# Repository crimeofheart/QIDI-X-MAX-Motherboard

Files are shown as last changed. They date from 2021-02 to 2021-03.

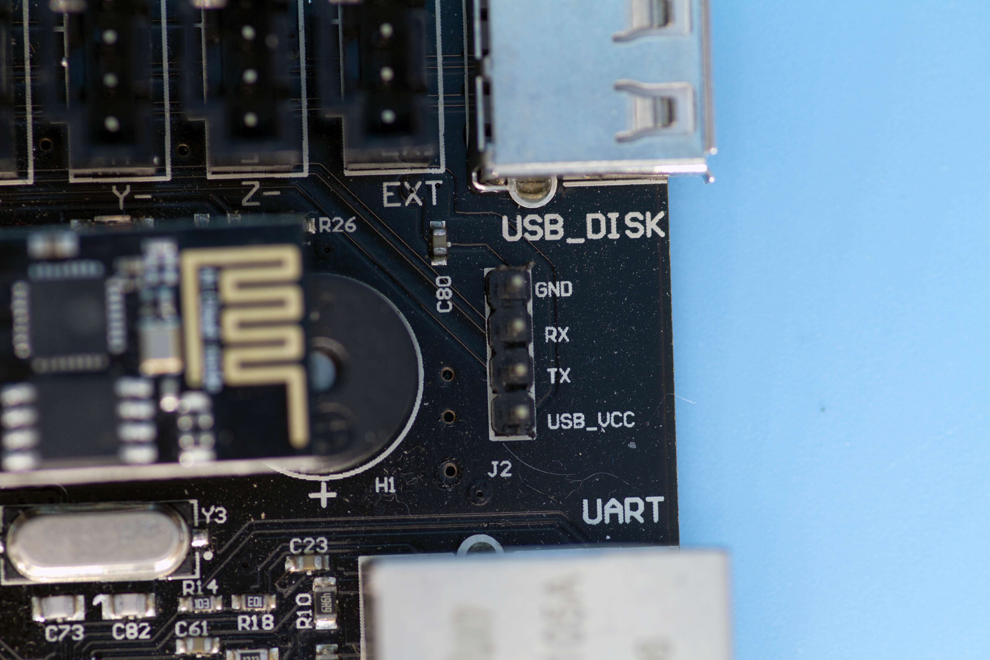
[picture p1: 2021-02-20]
Images/UART for USB to serial raspberry connection.jpg

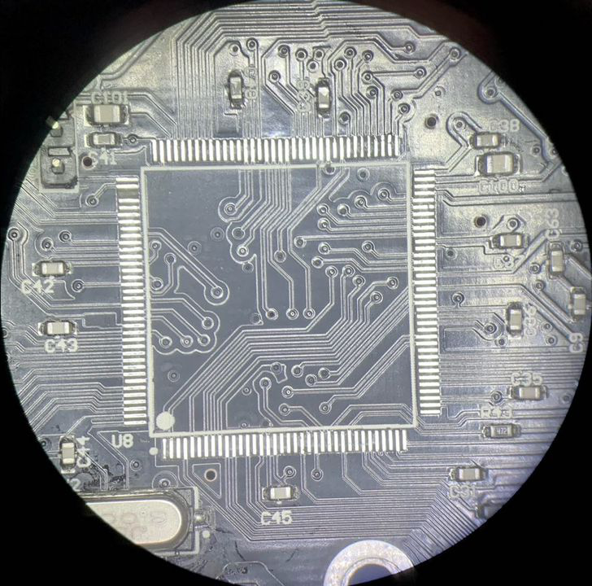
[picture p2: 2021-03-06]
Images/PCB Under STM32.jpg

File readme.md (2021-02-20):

QIDI X-MAX Motherboard Project
Starting

To download this project to your computer:

    Install GIT: https://git-scm.com/downloads
    Go into your main project directory, open commad line and run:
    git clone https://github.com/your_username/your_project.git

Using Git in Altium

    Save: Once you make any changes, save the file or project
    Commit: Right click on the file or project, then Version Control -> Commit. Add a note what changes you have done. This not will be still local until you do not push the changes. See the next step.
    Push: When you would like to upload all the changes to github, right click on the file / project -> Version Control -> Push
    Check: Go to your github to see if everything was uploaded correctly

Using Git from command line (Manually)

    Open cmd: Once you make some updates, go into your project directory, open commad line and run:
    git status #this will show you what changes you have done
    git add [path/file] #this will prepare that specific file for commit, to add all files at once, use add .
    git commit -m "Change description" #this will commit the changes with specific description
    git push origin master # this will copy your changes to Github

Download the latest changes

If you would like to download the latest files from Github, then:

    git pull origin master # this will download the latest files from Github to your local computer

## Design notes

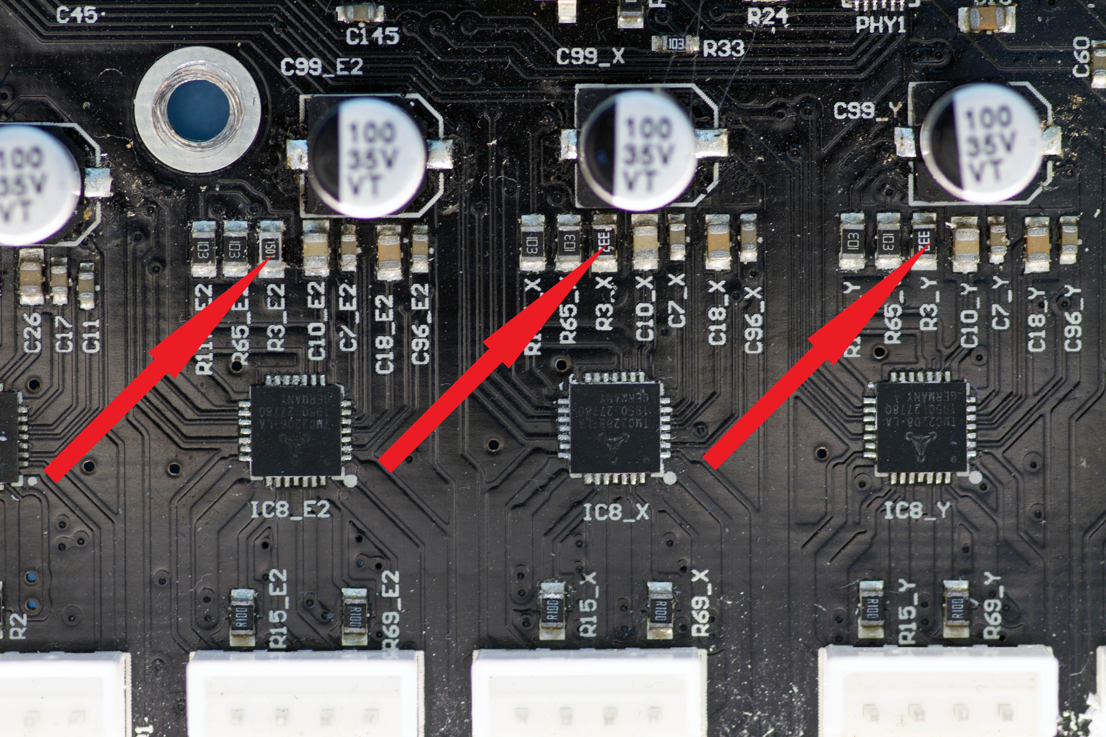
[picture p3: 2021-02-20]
Images/Motor drivers TMC2208.jpg

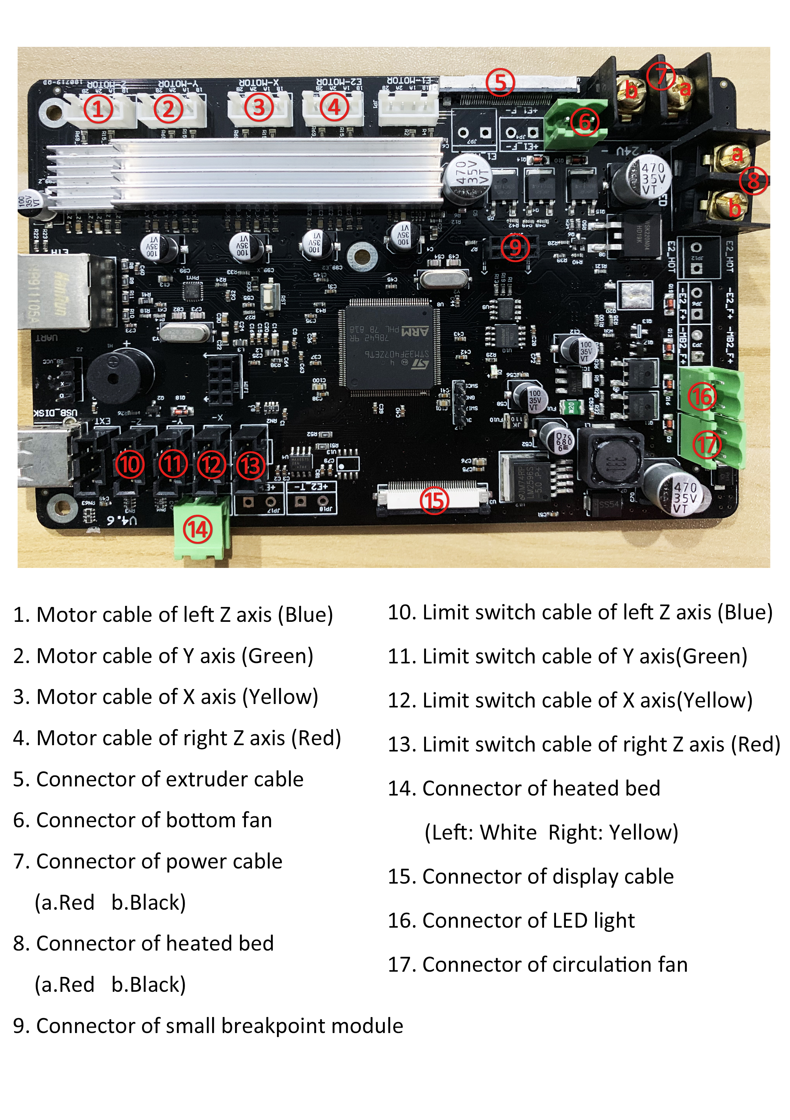
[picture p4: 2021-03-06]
Images/x-plus max mainboard connetion.jpg

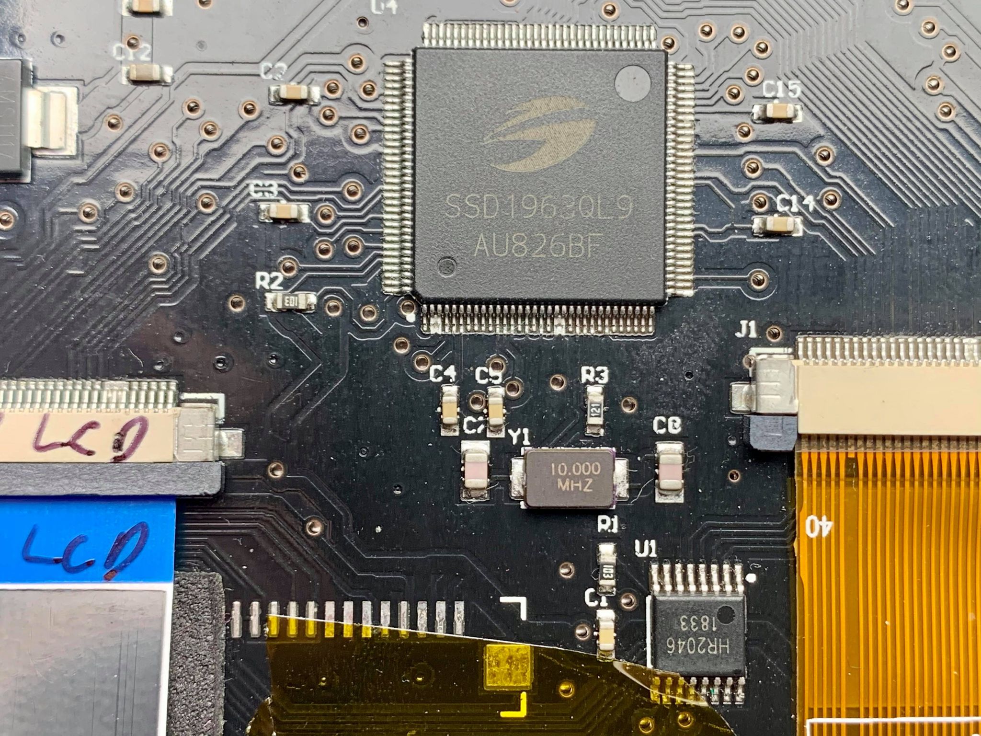
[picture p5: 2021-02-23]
Images/SSD1963QL9 LCD Driver.jpg

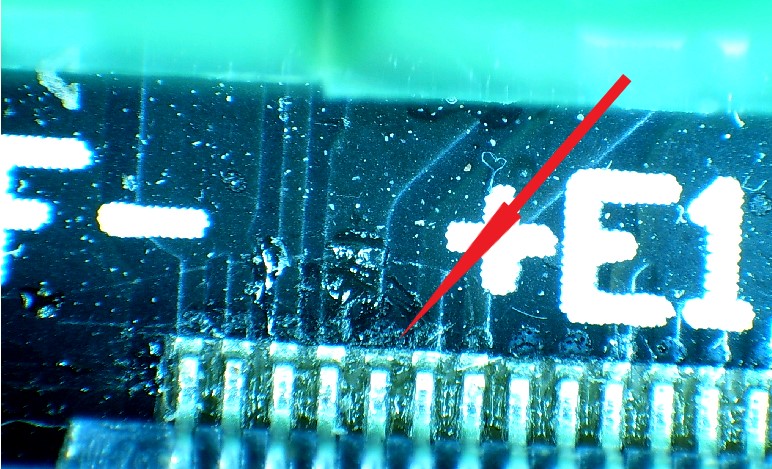
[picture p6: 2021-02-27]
Images/bed level sensor.jpg

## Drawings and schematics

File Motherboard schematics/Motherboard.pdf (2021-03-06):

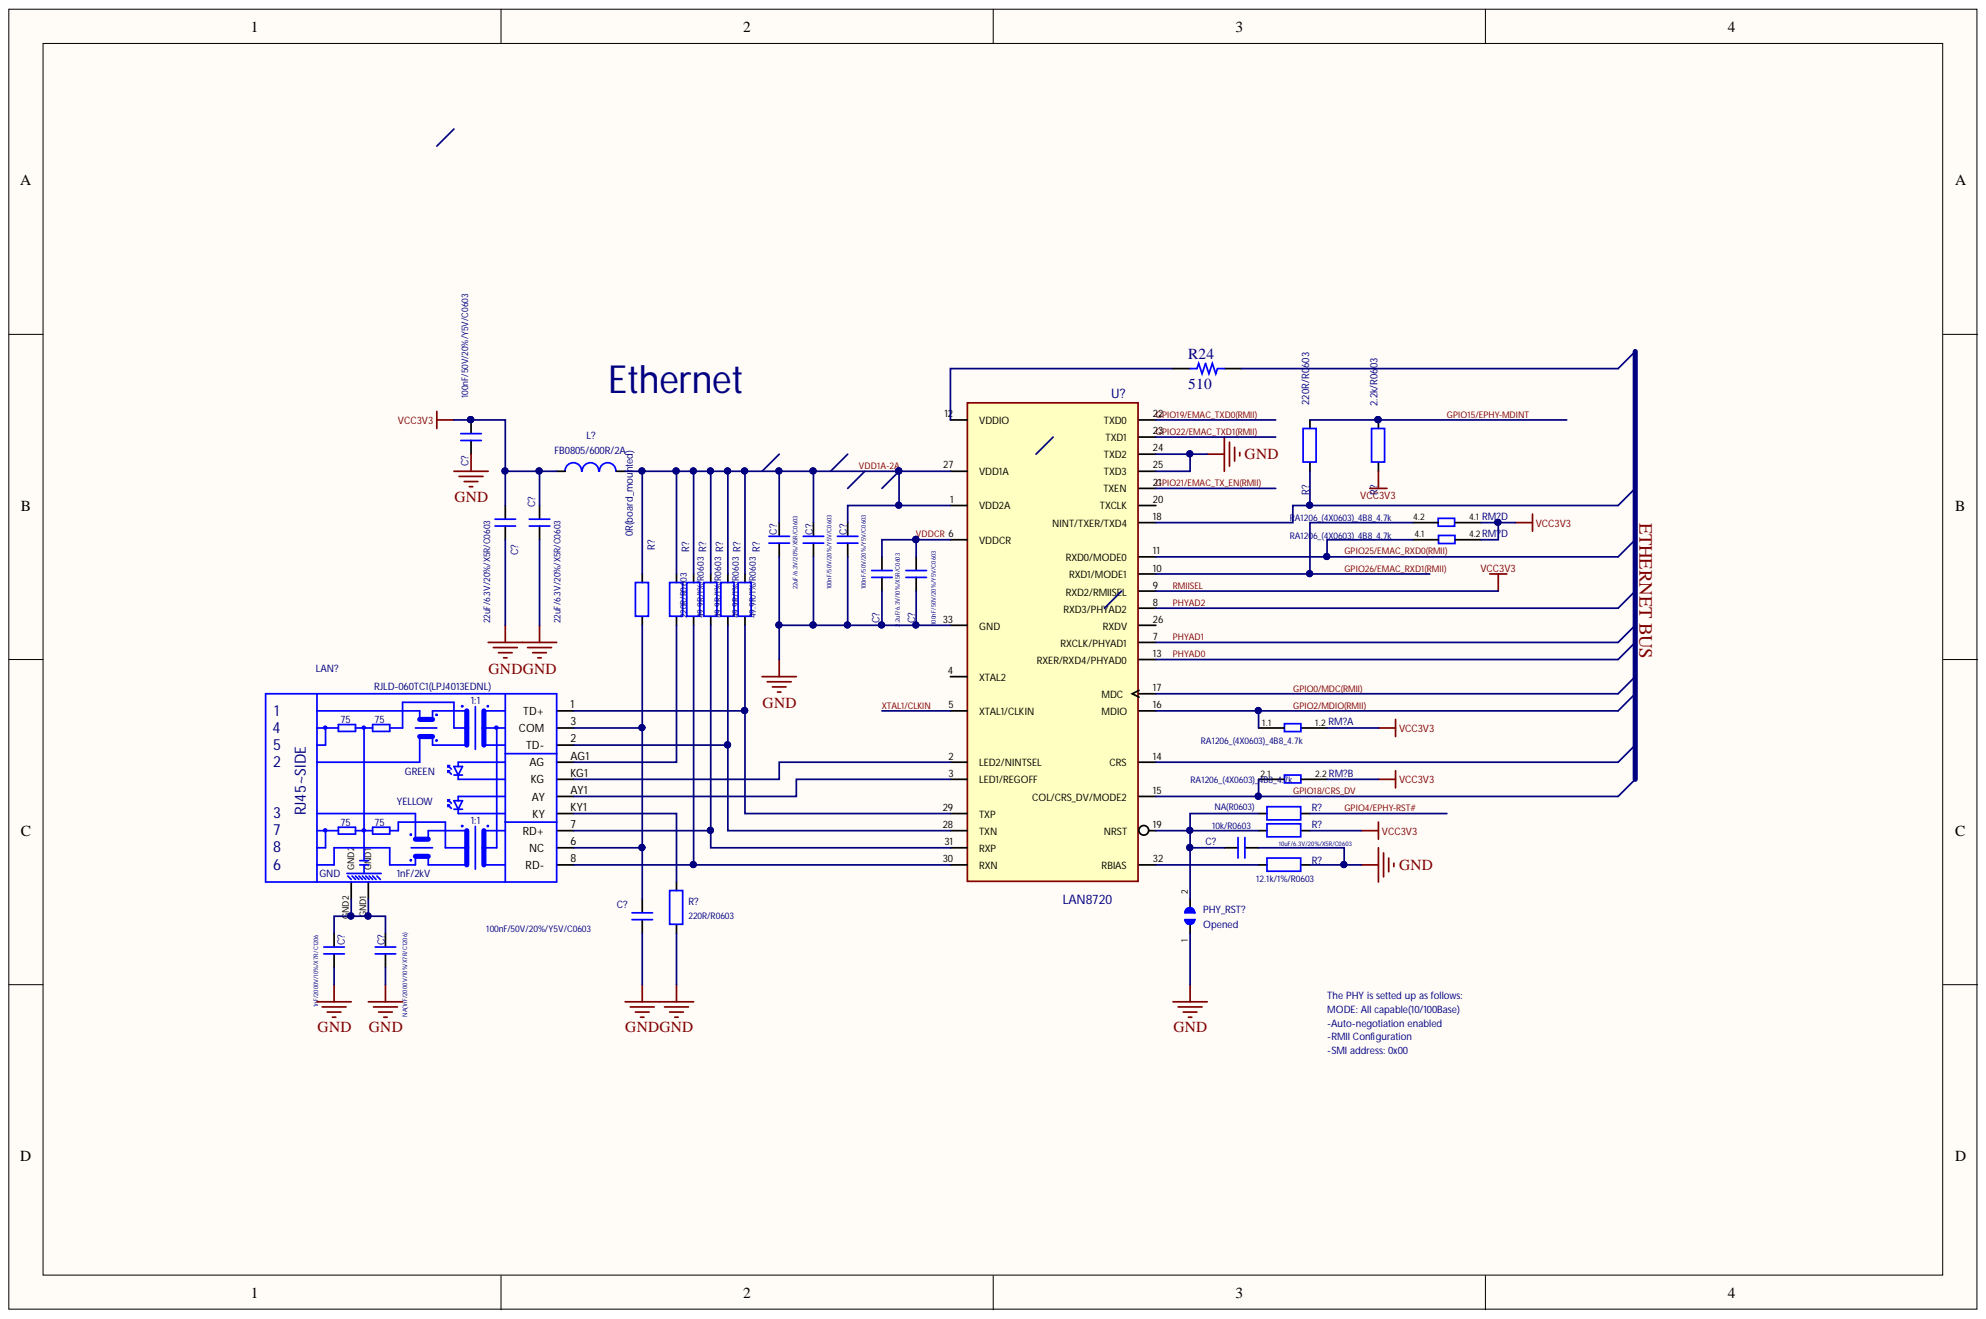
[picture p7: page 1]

V D DCR 6 | | RA1 206_(4X0603)_4B 1 1 | 8_4.7k | 0(RM I I )

A G 1

A Y 1
KY 1 | | 29

Y is setted up as fol

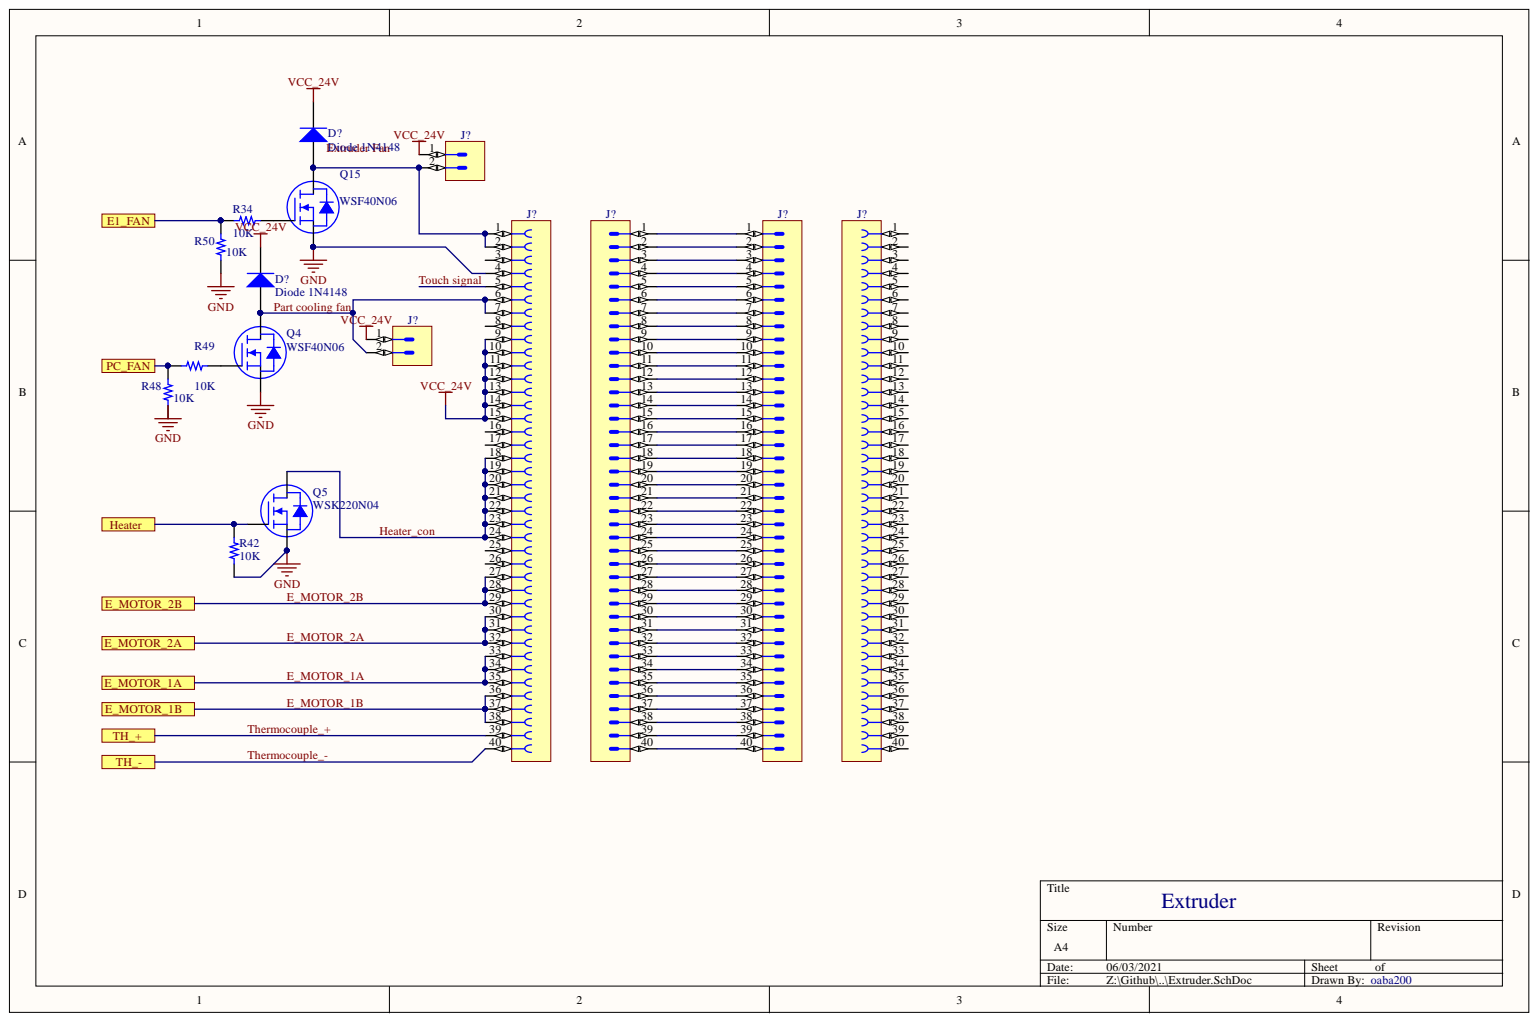
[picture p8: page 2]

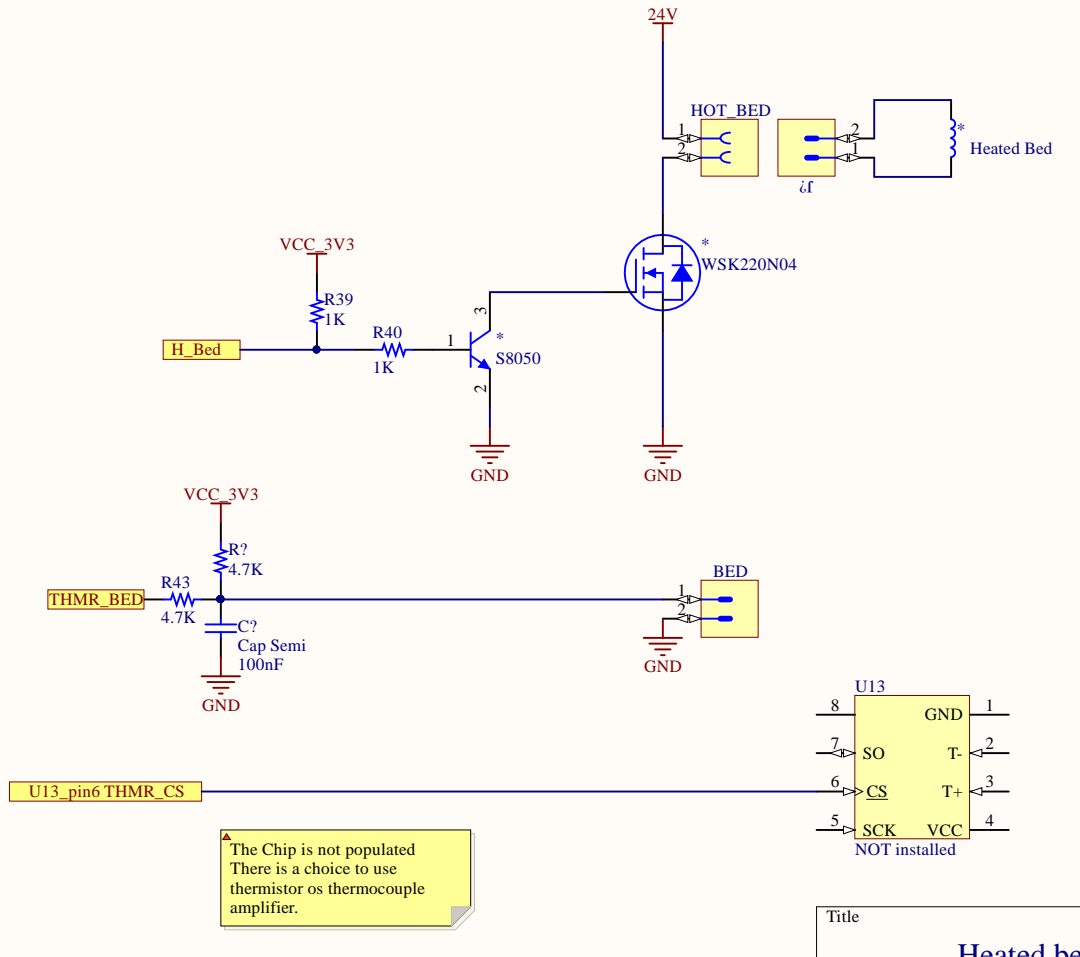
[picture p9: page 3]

The Chip is not populated
There is a choice to use
thermistor os thermocouple
amplifier.

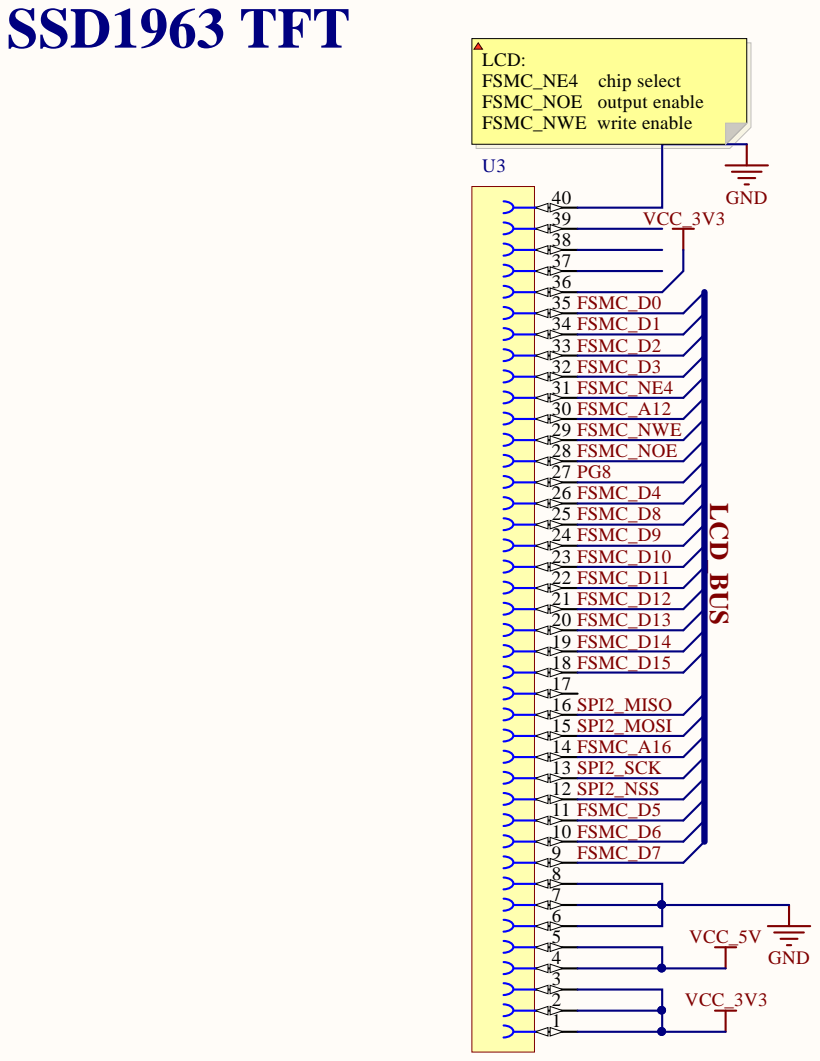
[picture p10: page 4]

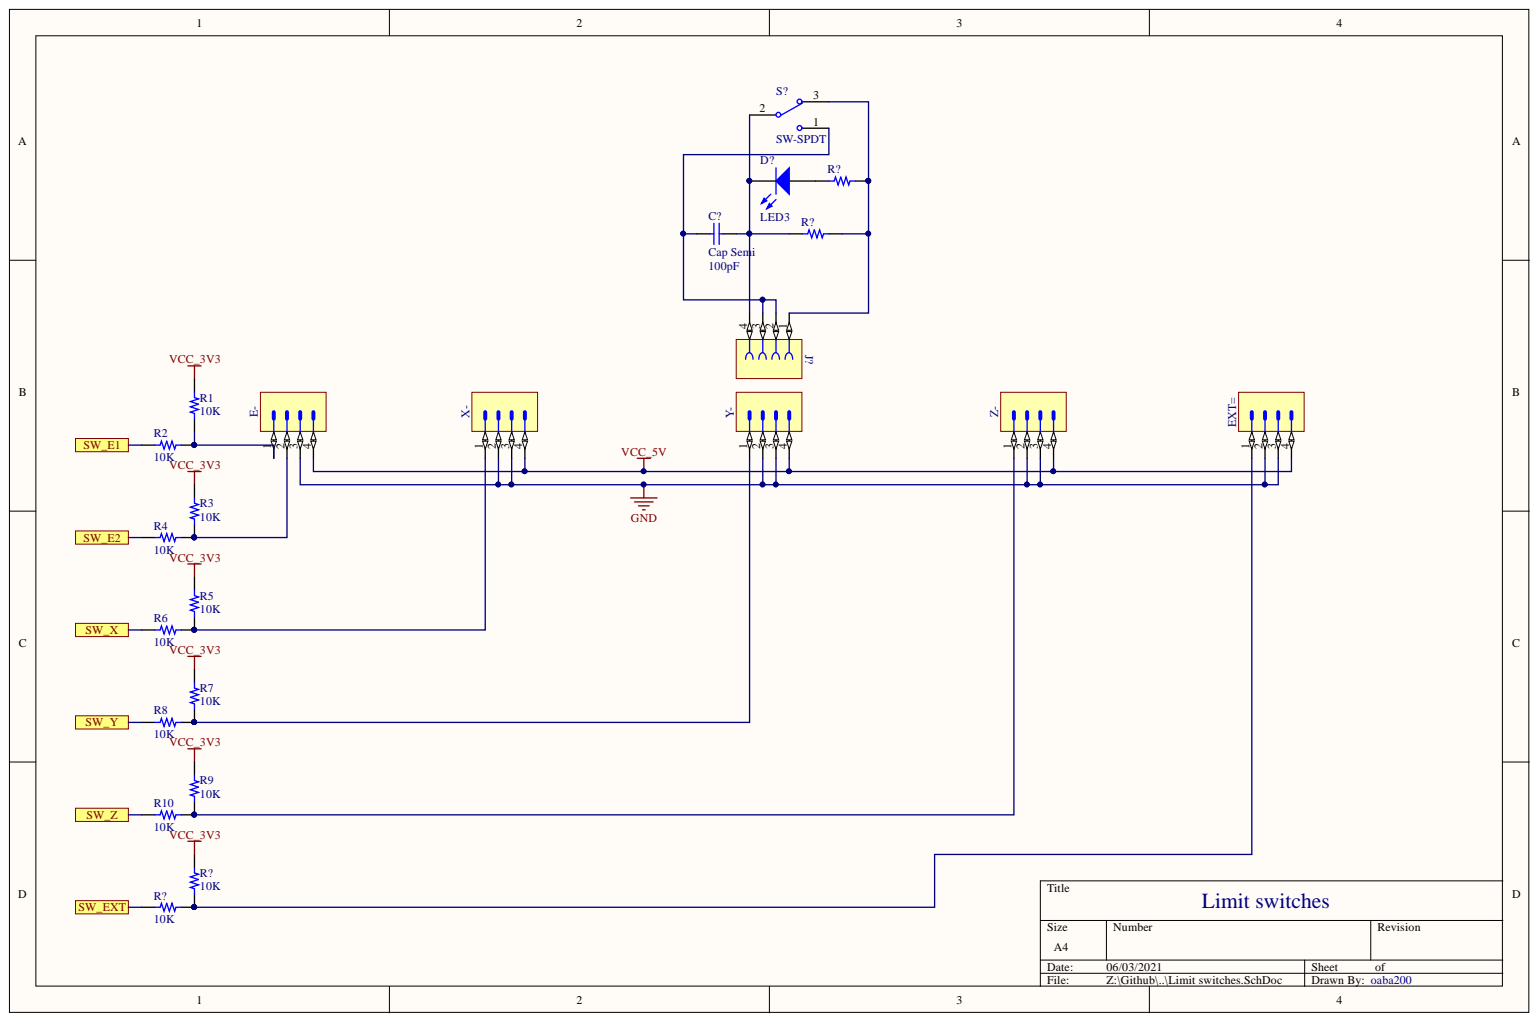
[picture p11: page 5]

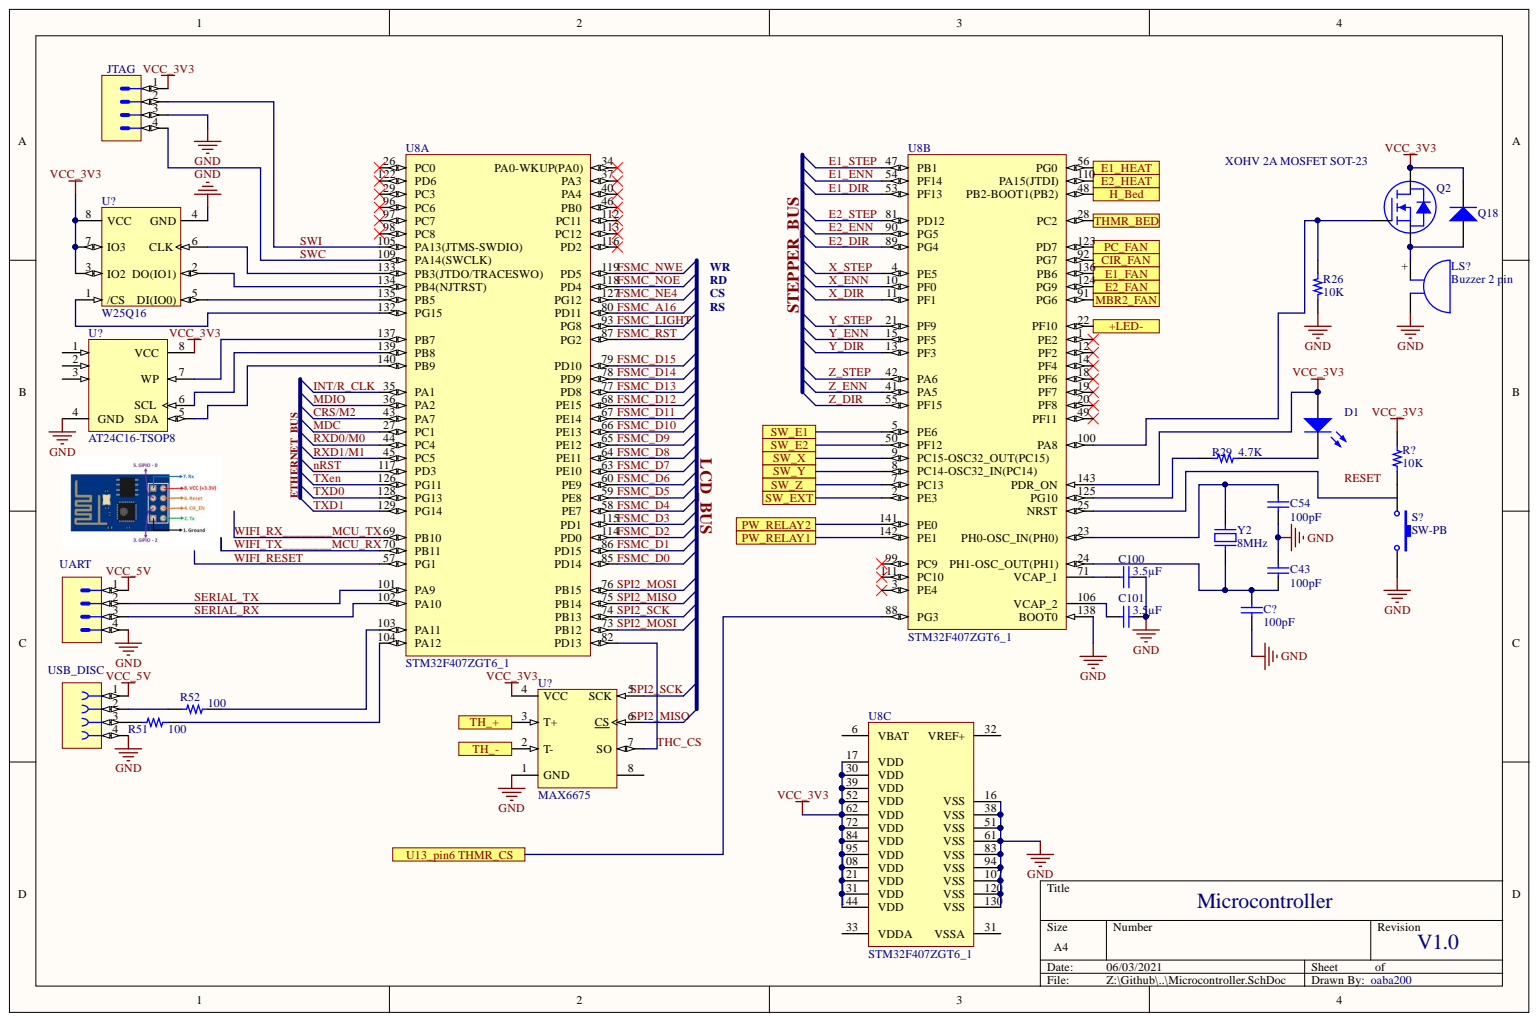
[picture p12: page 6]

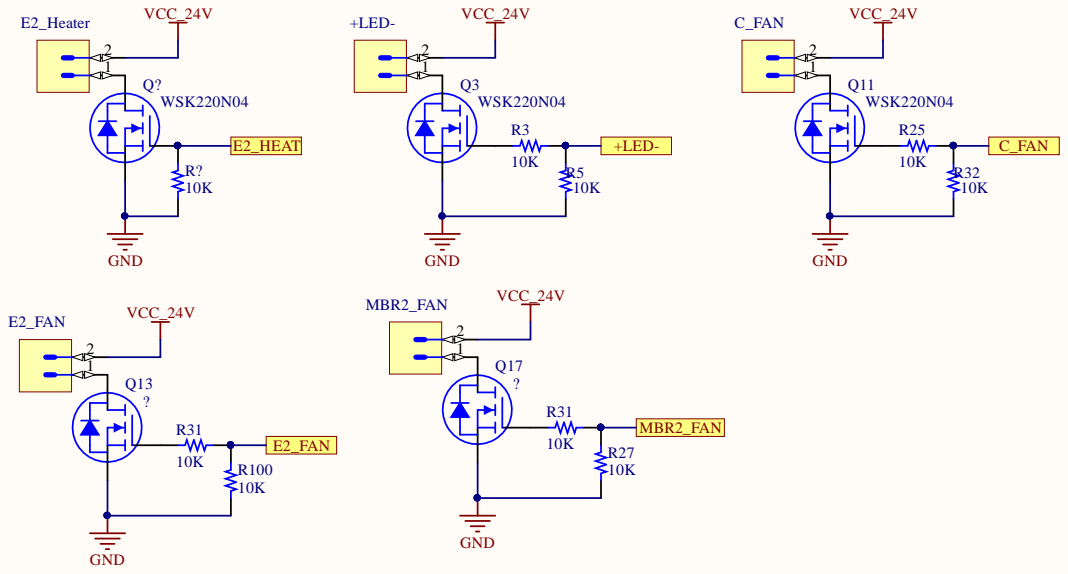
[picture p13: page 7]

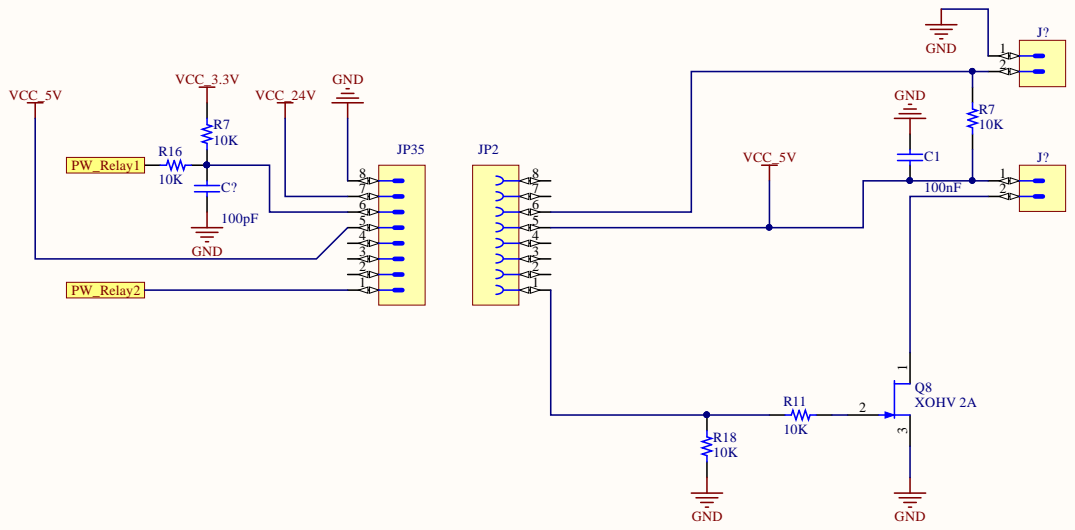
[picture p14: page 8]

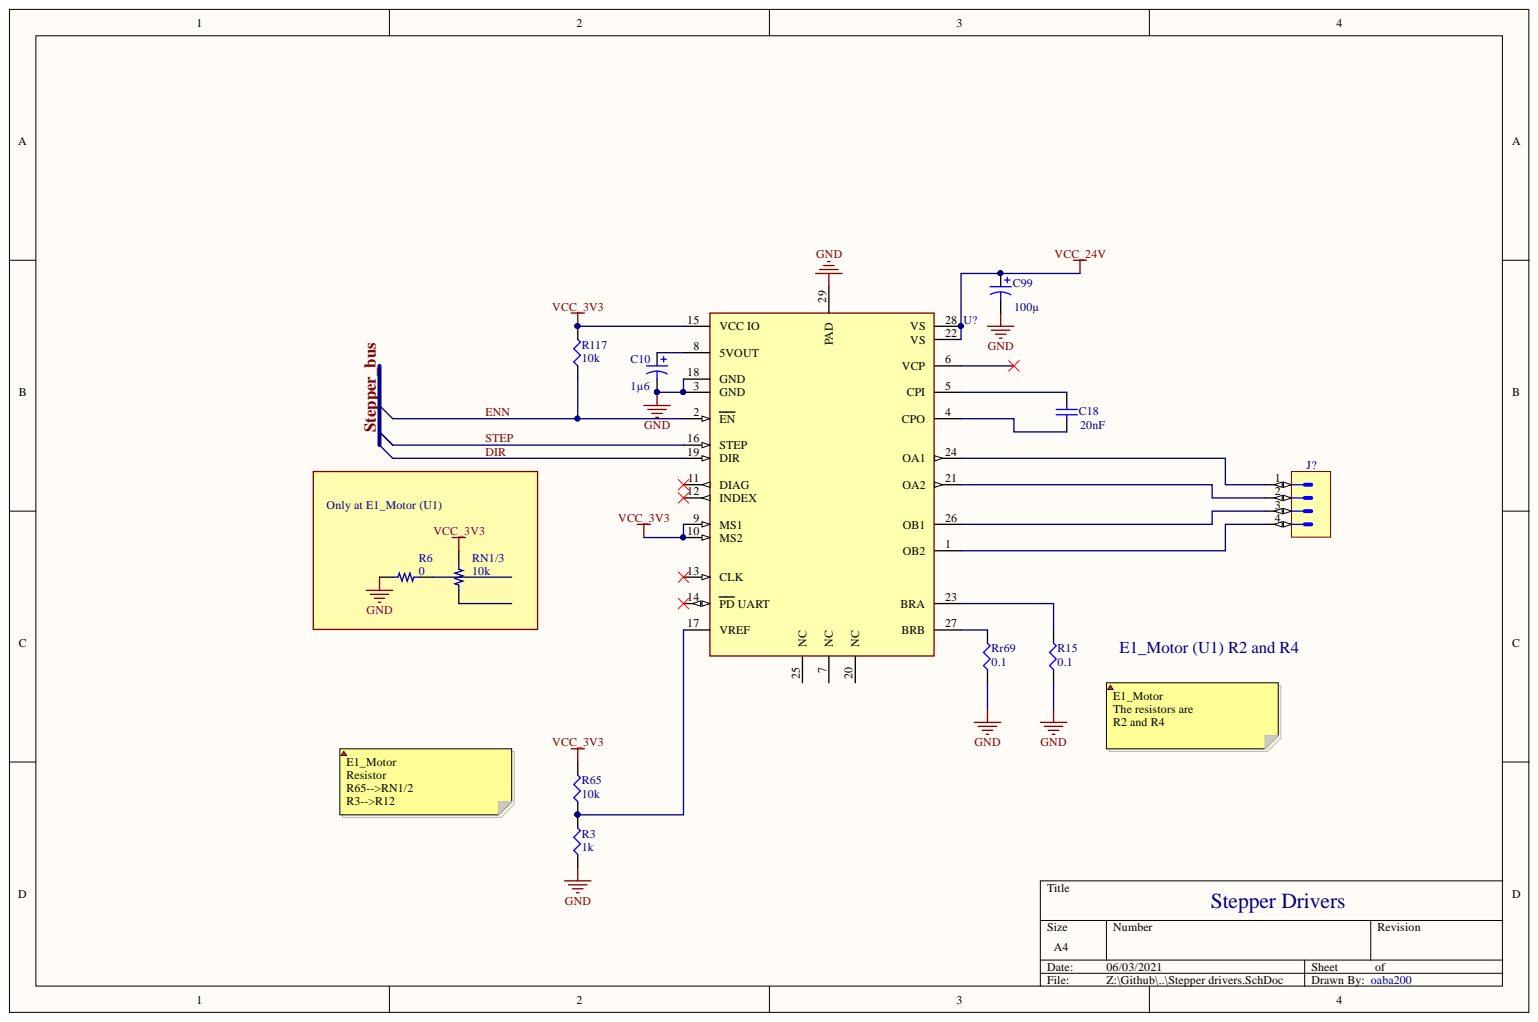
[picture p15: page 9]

Comment | Description | Designator | Footprint | LibRef | Quantity
Heated Bed | | | | Heater coil | 1
S8050 | | | SOT23 | S8050 | 1
=Family | Connector 2 Male, Connector 4 Male, Connector 2 Female, Connector 40 Female, Connector 40 Male, Connector 4 Female, Connector 8 Female, Connector 8 Male | +LED-, BED, C_FAN, E-, E2_FAN, E2_Heater, EXT=, HOT_BED, J?, JP2, JP35, JTAG, MBR2_FAN, U3, UART, USB_DISC, X-, Y-, Z- | | Connector 2 Male, Connector 4 Male, Connector 2 Female, Connector 40 Female, Connector 40 Male, Connector 4 Female, Connector 8 Female, Connector 8 Male | 29
Cap Pol3 | Polarized Capacitor (Surface Mount) | C10, C99 | C0805 | Cap Pol3 | 2
1nF/2000V/10%/X7R/C1 206 | | C? | C_1206_5MIL_DWS_ISO | C | 1
2.2uF/6.3V/10%/X5R/C0 603 | | C? | C_0603_5MIL_DWS | C | 1
10uF/6.3V/20%/X5R/C0 603 | | C? | C_0603_5MIL_DWS | C | 1
22uF/6.3V/20%/X5R/C0 603 | | C? | C_0603_5MIL_DWS | C | 3
100nF/50V/20%/Y5V/C0 603 | | C? | C_0603_5MIL_DWS | C | 5
NA(1nF/2000V/10%/X7R /C1206) | | C? | C_1206_5MIL_DWS_ISO | C | 1
Cap Semi | Capacitor (Semiconductor SIM Model) | C?, C1, C18, C43, C54, C100, C101 | C1206 | Cap Semi | 10
LED3 | Typical BLUE SiC LED | D?, D1 | 3.5X2.8X1.9 | LED3 | 2
Diode 1N4148 | High Conductance Fast Diode | D?, Q18 | DO-35 | Diode 1N4148 | 3
FB0805/600R/2A | | L? | L_0805_5MIL_DWS | L | 1
RJLD-060TC1(LPJ4013EDNL) | | LAN? | RJLBC-060TC1 | RJLBC-060TC1_GND | 1
Buzzer 2 pin | | LS? | | Buzzer 2 pin | 1
Opened | | PHY_RST? | SJ | SJ | 1
XOHV 2A MOSFET SOT-23 | | Q2 | | XOHV 2A MOSFET SOT-23 | 1
WSF40N06 | N-Ch MOSFET 40V 220A | Q4, Q15 | TO263 | WSK220N04 | 2
XOHV 2A | N-Channel JFET | Q8 | TO-254-AA | JFET-N | 1
? | N-Ch MOSFET 40V 220A | Q13, Q17 | TO263 | WSK220N04 | 2
1k | RES SMD 10K OHM 5% 1/10W 0402 | R3 | SMD-0402-RES | ERJ-2GEJ103X | 1
0 | SMT Resistor | R6 | RES 0805_2012 | Resistor | 1
0.1 | RES SMD 0.11 OHM 1% 1/6W 0402 | R15, Rr69 | SMD-0402-RES | ERJ-2BSFR11X | 2
510 | SMT Resistor | R24 | RES 0805_2012 | Resistor | 1
1K | SMT Resistor | R39, R40 | | Resistor | 2
100 | SMT Resistor | R51, R52 | RES 0805_2012 | Resistor | 2
10k | RES SMD 10K OHM 5% 1/10W 0402, RES SMD 20K OHM 5% 1/10W 0402 | R65, R117 | SMD-0402-RES | ERJ-2GEJ103X, ERJ-2GEJ203X | 2
0R(board_mounted) | | R? | 0R_0603 | R | 1
2.2k/R0603 | | R? | R_0603_5MIL_DWS | R | 1
10k/R0603 | | R? | R_0603_5MIL_DWS | R | 1
12.1k/1%/R0603 | | R? | R_0603_5MIL_DWS | R | 1
49.9R/1%/R0603 | | R? | R_0603_5MIL_DWS | R | 4
220R/R0603 | | R? | R_0603_5MIL_DWS | R | 3
=VALUE | SMT Resistor | R? | RES 0805_2012 | Resistor | 2
NA(R0603) | | R? | R_0603_5MIL_DWS | R | 1
10K | SMT Resistor | R?, R1, R2, R3, R4, R5, R6, R7, R8, R9, R10, R11, R16, R18, R25, R26, R27, R31, R32, R34, R42, R48, R49, R50, R100, RN1/3 | RES 0805_2012 | Resistor | 34
4.7K | SMT Resistor | R?, R29, R43 | RES 0805_2012 | Resistor | 3
RA1206_(4X0603)_4B8_4 .7k | | RM? | R_MATRIX_4 | RA1206_(4x0603)_4B8_S mashed | 4
SW-PB | Switch | S? | SPST-2 | SW-PB | 1
SW-SPDT | SPDT Subminiature Toggle Switch, Right Angle Mounting, Vertical Actuation | S? | TL36WW15050 | SW-SPDT | 1
STM32F407ZGT6_1 | V2 ARM Cortex-M4 32-bit MCU+FPU, 210 DMIPS, 1024 kB Flash, 192 kB Internal RAM, 114 I/Os, 144-pin LQFP, 40 to 85 degC, Tray | -U8 | STM-LQFP144_N | STM32F407ZGT6_1 | 1
NOT installed | | U13 | SOIC8 | MAX6675 | 1
AT24C16-TSOP8 | 1Kbit (128 x 8), 2-wire Bus Automotive Serial EEPROM with Write Protect, 2.5V, 8-Pin TSSOP, Bulk | U? | 8A2_N | AT24C16-TSOP8 | 1
LAN8720 | | U? | QFN32_EP(33)_5.00x5.00 x0.90mm_Pitch_0.50mm | LAN8720 | 1
MAX6675 | | U? | SOIC8 | MAX6675 | 1
TMC2208-LA | | U? | | TMC2208-LA | 1
W25Q16 | FLASH - NOR Memory IC 16Mb _2M x 8_ SPI 104MHz 8-SOIC | U? | SOIC8 | W25Q16 | 1
8MHz | SMT Crystal | Y2 | | Abracon Crystal ABS06 | 1
WSK220N04 | N-Ch MOSFET 40V 220A | [NoValue], Q?, Q3, Q5, Q11 | TO263 | WSK220N04 | 5

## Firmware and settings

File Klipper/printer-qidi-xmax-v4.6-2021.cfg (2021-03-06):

# This is a Klipper configuration for Qidi X-Max, with
# V4.6 motherboard. originate Funkton modifyed By oaba200


#            === FLASHING WITH STOCK BOOTLOADER ===
# You should make firmware for STM32F407 with bootloader offset
# at ??????. Uncheck USB, and leave default
# serial settings. USART1
# 
# Use "./scripts/update_chitu.py ./out/klipper.bin ./out/update.qd" after make to generate update.qd.
# Put `update.cbd` onto SD card, and reboot the printer.
# It will be automatically installed, and you will be able to update it this way.
# !! Qidi update may require selecting on touchscreen. Double check

[mcu]
restart_method: command
serial: dev/serial0
# CONFIG_SERIAL_PORT == 1 setup for PA9, PA10
# setup for PA9, PA10 USART1_tx / rx directly connected to the RPI GPIO TX / RX pins
# These are the pins the GTR uses for its built in RPI 40 pin connector
# only connect GND, TX, RX - supply 5v power to the RPI separately
# cross over TX/RX
# Use "sudo raspi-config" to disable the serial terminal - but enable the serial port.
# When running "make menuconfig" you must un-select the USB Serial check box

#FLUIDD Required configs
[virtual_sdcard]
path: ~/gcode_files
[display_status]
[pause_resume]

[gcode_macro PAUSE]
rename_existing: BASE_PAUSE
default_parameter_X: 230    # edit to your preferred park position
default_parameter_Y: 230    # edit to your preferred park position
default_parameter_Z: 10     # edit to your preferred park position
default_parameter_E: 1      # edit to your preferred retract length
gcode:
    SAVE_GCODE_STATE NAME=PAUSE_state
    BASE_PAUSE
    G91
    G1 E-{E} F2100
    G1 Z{Z}
    G90
    G1 X{X} Y{Y} F6000
    
[gcode_macro RESUME]
rename_existing: BASE_RESUME
default_parameter_E: 1      # edit to your preferred retract length
gcode:
    G91
    G1 E{E} F2100
    G90
    RESTORE_GCODE_STATE NAME=PAUSE_state MOVE=1
    BASE_RESUME

[gcode_macro CANCEL_PRINT]
rename_existing: BASE_CANCEL_PRINT
gcode:
    TURN_OFF_HEATERS
    CLEAR_PAUSE
    SDCARD_RESET_FILE
    BASE_CANCEL_PRINT
    
#Printer settings X-Max

[printer]
kinematics: cartesian
max_velocity: 300
max_accel: 3000
max_z_velocity: 15
max_z_accel: 5
square_corner_velocity: 3.0

[stepper_x]
step_pin: PE5
dir_pin: !PF1
enable_pin: !PF0
microsteps: 16
rotation_distance: 20
endstop_pin: !PC15
position_endstop: 300
position_min: 0
position_max: 300
homing_retract_dist: 10
homing_speed: 30
second_homing_speed: 10

[stepper_y]
step_pin: PF9
dir_pin: !PF3
enable_pin: !PF5
microsteps: 16
rotation_distance: 20
endstop_pin: !PC14
position_endstop: 250
position_max: 250
homing_retract_dist: 10
homing_speed: 30
second_homing_speed: 10

[stepper_z]
step_pin: PA6
dir_pin: PF15
enable_pin: !PA5
microsteps: 16
rotation_distance: 8
endstop_pin: !PC13
position_endstop: 300
position_max: 300
position_min: 0
homing_retract_dist: 5
homing_speed: 12
second_homing_speed: 1

[stepper_z1]
step_pin: PD12
dir_pin: PG4
enable_pin: !PG5
microsteps: 16
rotation_distance: 8
endstop_pin: !PF12

[extruder]
step_pin: PB1
dir_pin: PF13
enable_pin: !PF14
microsteps: 16
rotation_distance: 35.520
nozzle_diameter: 0.400
filament_diameter: 1.750
#max_extrude_cross_section: 7
#max_extrude_only_velocity:
#max_extrude_only_accel:
#pressure_advance: 0.0
#pressure_advance_smooth_time: 0.040
heater_pin: PG0
sensor_type: MAX6675
sensor_pin: PD13 #SO
spi_bus: spi2
spi_software_miso_pin: PB13 #Chipselect
spi_software_sclk_pin: PB14 #SCK
# spi_software_mosi_pin: PB15
spi_speed: 4000000 
control: pid
pid_Kp: 18
pid_Ki: 1.08
pid_Kd: 98
min_extrude_temp: 170
min_temp: 0
max_temp: 290
max_extrude_only_distance: 300

[heater_bed]
heater_pin: PB2
sensor_type: EPCOS 100K B57560G104F
sensor_pin: PC2
control: pid
min_temp: 0
max_temp: 130
pid_Kp: 73.932
pid_Ki: 1.521
pid_Kd: 898.279

[heater_fan hotend_fan]
pin: PB6
fan_speed: 0.9
heater: extruder
heater_temp: 70.0

[fan]
pin: PD7
max_power: 1
off_below: 0.1

#[controller_fan drivers_fan]
#pin: PD6


[output_pin beeper]
pin: PA8

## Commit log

2021-02-20 Add value for the document Title
    [LCD Screen.SchDoc]
2021-02-20 Added firmware details
    Added firmware file
    Added fuse information
    Added mem location
2021-02-20 Added Limit Switches
    [Limit switches.SchDoc, Microcontroller.SchDoc, Motherboard.PrjPcb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]
2021-02-20 Added Switch ext
    [Limit switches.SchDoc, Microcontroller.SchDoc]
2021-02-21 Added resistor value for the reset circuit
    [Microcontroller.SchDoc]
2021-02-21 Added PW_Relay control board
    [Motherboard.PrjPcb, Motherboard.SchLib, Relay controll extension board v1.5.SchDoc]
2021-02-21 Added clock source
    [Microcontroller.SchDoc, Relay controll extension board v1.5.SchDoc]
2021-02-21 Modified crystal
    [Microcontroller.SchDoc]
2021-02-21 Memory content added
    Upload EEPROM and Flash memory content from a fresh new board
2021-02-21 Added flash memory for schematic
    [Microcontroller.SchDoc, Motherboard.PcbLib, Motherboard.SchLib]
2021-02-21 Added WIFI module
    [Microcontroller.SchDoc]
2021-02-21 Wifi connected
    [Microcontroller.SchDoc]
2021-02-23 Connected thermocouple IC
    [Microcontroller.SchDoc]
2021-02-23 USB port added
    [Microcontroller.SchDoc]
2021-02-23 Added Network Schematic
    [Ethernet.SchDoc, Motherboard.PrjPcb, Motherboard.SchLib]
2021-02-23 Changed ground and power
    [Ethernet.SchDoc, Motherboard.SchLib]
2021-02-23 Create SSD1963QL9 LCD Driver.jpg
2021-02-27 Added buzzer
    [Microcontroller.SchDoc, Motherboard.SchLib]
2021-02-27 Added diode q18
    [Microcontroller.SchDoc]
2021-02-27 Added stepper driver enable pins
    [Microcontroller.SchDoc, Stepper drivers.SchDoc]
2021-02-27 Some other leg
    [Microcontroller.SchDoc]
2021-02-27 klipper config fix
    [printer-qidi-xmax-v4.6-2021(1).cfg]
2021-02-27 modified pins
    [printer-qidi-xmax-v4.6-2021(1).cfg]
2021-02-27 come mod on the config
    [printer-qidi-xmax-v4.6-2021(1).cfg]
2021-02-27 Create Bootloader for STM32F4xx.txt
2021-02-27 Firmware docs
    [Microcontroller.SchDoc]
2021-02-27 Create AN2606 STM32 Boot mode.pdf
2021-03-03 Added outputs
    [Extruder.SchDoc, Microcontroller.SchDoc, Motherboard.PrjPcb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]
2021-03-03 Ethernet connections
    [Ethernet.SchDoc, Microcontroller.SchDoc]
2021-03-05 Simplified microcontroller layout by reorganize pins
    [Extruder.SchDoc, Microcontroller.SchDoc, Motherboard.PrjPcb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]
2021-03-05 Added JTAG
    [Microcontroller.SchDoc, Motherboard.SchLib]
2021-03-06 Reorganized ethernet pins
    [Ethernet.SchDoc, Microcontroller.SchDoc, Motherboard.PrjPcb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]
2021-03-06 Jtag fixed and NC pins added
    [Microcontroller.SchDoc, Motherboard.SchLib]
2021-03-06 Create PCB Under STM32.jpg
2021-03-06 Heated bed sensor pin fixed. Added some NC pin
    [Microcontroller.SchDoc, Motherboard.SchLib]
2021-03-06 Added some new picture
    [printer-qidi-xmax-v4.6-2021.cfg]
2021-03-06 Re organized Ethernet pins
    [Microcontroller.SchDoc, Motherboard.SchLib]
2021-03-06 Reorganized Display pins
    [Microcontroller.SchDoc, Motherboard.SchLib]
2021-03-06 Adjusted pin127
    [Microcontroller.SchDoc]
2021-03-06 Added thermistor amplifier
    [Heated bed.SchDoc, Microcontroller.SchDoc, Motherboard.SchLib]
2021-03-06 NC pin corrected
    [Microcontroller.SchDoc]
2021-03-06 Updated titels and PDF output
    [Ethernet.SchDoc, Extruder.SchDoc, Heated bed.SchDoc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]
2021-03-06 Some extra notes
    [Stepper drivers.SchDoc]
2021-03-06 Stepper driver PDF
    [Stepper drivers.SchDoc]
2021-03-06 Extruder conector PDF
    [Extruder.SchDoc]
